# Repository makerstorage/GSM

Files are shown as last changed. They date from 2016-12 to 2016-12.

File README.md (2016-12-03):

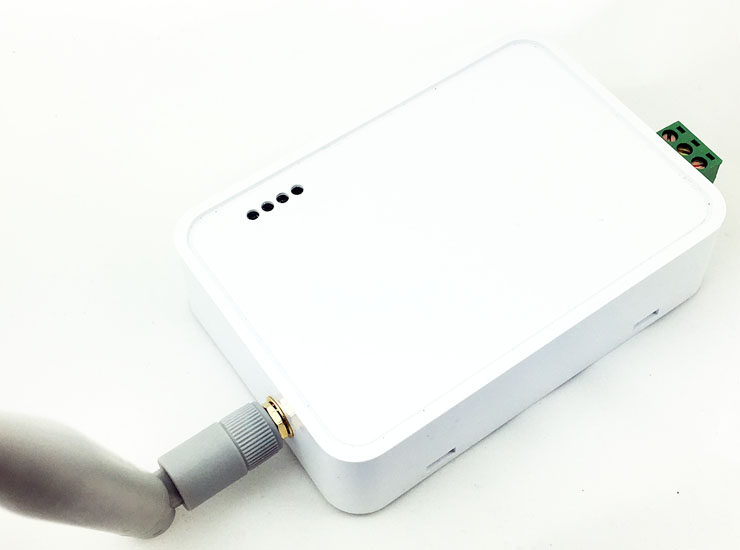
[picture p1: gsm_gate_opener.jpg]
GSM Gate Opener


**GSM Gate Opener**

For more details, check out the blog pages at

http://blog.makerstorage.com

MakerStorage invests time and resources providing this open source design, please support MakerStorage and open-source hardware by purchasing products from MakerStorage!

Designed by MakerStorage LLC.

Creative Commons Attribution, Share-Alike license, check https://creativecommons.org/licenses/by-sa/3.0/ for more information All text above must be included in any redistribution

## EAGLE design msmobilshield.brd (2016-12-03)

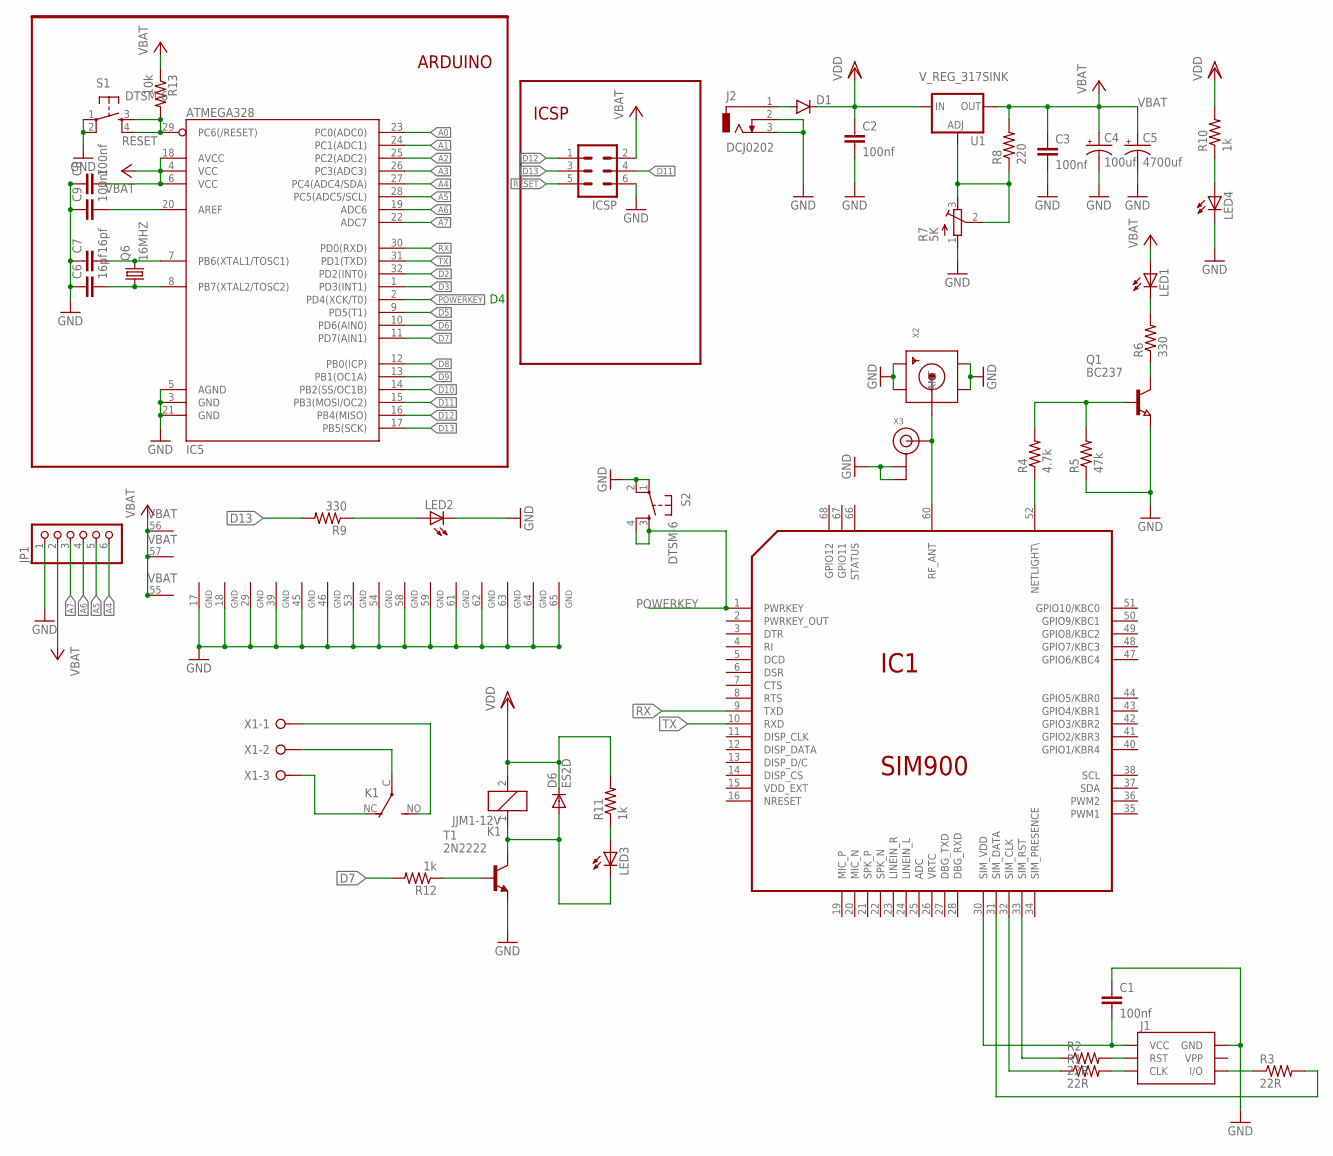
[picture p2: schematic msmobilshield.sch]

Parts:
C1, C2, C3, C8, C9: 100nf; C0805
C4: 100uf; CPOL-RADIAL-100UF-25V
C5: 4700uf; CPOL-RADIAL-1000UF-25V
C6, C7: 16pf; C0805
D1: DIODESMA; SMA-DIODE
D6: ES2D; SMB
IC1: SIM900
IC5: ATMEGA328; TQFP32-08
ICSP: ML6
J1: SIMHOLDERSIM; SIMHOLDER
J2: DCJ0202
JP1: PINHD-1X6; 1X06
K1: JJM1-12V; JJM1C
LED1, LED2, LED3, LED4: LEDCHIPLED_0805; CHIPLED_0805
Q1: BC237; SOT23
Q6: 16MHZ; HC49/S
R1, R2, R3: 22R; R0805
R4: 4.7k; R0805
R5: 47k; R0805
R6, R9: 330; R0805
R7: 5K; RTRIM3103
R8: 220; R0805
R10, R11, R12: 1k; R0805
R13: 10k; R0805
S1, S2: DTSM-6
T1: 2N2222; SOT23-BEC
U1: V_REG_317SINK; TO220-ADJ
X1: W237-3E
X2: SMACONNECTOR; SMA90_DIP
X3: ANTENNA_U.FL; U.FL

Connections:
A0: IC5.23 (PC0(ADC0))
A1: IC5.24 (PC1(ADC1))
A2: IC5.25 (PC2(ADC2))
A3: IC5.26 (PC3(ADC3))
A4: IC5.27 (PC4(ADC4/SDA)), JP1.6
A5: IC5.28 (PC5(ADC5/SCL)), JP1.5
A6: IC5.19 (ADC6), JP1.4
A7: IC5.22 (ADC7), JP1.3
D2: IC5.32 (PD2(INT0))
D3: IC5.1 (PD3(INT1))
D5: IC5.9 (PD5(T1))
D6: IC5.10 (PD6(AIN0))
D7: IC5.11 (PD7(AIN1)), R12.2
D8: IC5.12 (PB0(ICP))
D9: IC5.13 (PB1(OC1A))
D10: IC5.14 (PB2(SS/OC1B))
D11: IC5.15 (PB3(MOSI/OC2)), ICSP.4
D12: IC5.16 (PB4(MISO)), ICSP.1
D13: IC5.17 (PB5(SCK)), ICSP.3, R9.2
GND: C1.1, C2.2, C3.2, C4.2 (-), C5.-, C6.1, C7.1, C8.1, C9.1, IC1.17 (GND), IC1.18 (GND), IC1.29 (GND), IC1.39 (GND), IC1.45 (GND), IC1.46 (GND), IC1.53 (GND), IC1.54 (GND), IC1.58 (GND), IC1.59 (GND), IC1.61 (GND), IC1.62 (GND), IC1.63 (GND), IC1.64 (GND), IC1.65 (GND), IC5.3 (GND), IC5.5 (AGND), IC5.21 (GND), ICSP.6, J1.C5 (GND), J2.2, J2.3, JP1.1, LED2.C, LED4.C, Q1.2 (E), R5.1, R7.1 (A), S1.1, S1.2, S2.1, S2.2, T1.E, X2.GND1, X2.GND2, X2.GND3, X2.GND4, X3.1 (GND), X3.2 (GND)
unnamed: J1.C2 (RST), R2.2
unnamed: J1.C3 (CLK), R1.2
unnamed: J1.C7 (I/O), R3.1
unnamed: IC1.33 (SIM_RST), R2.1
unnamed: IC1.32 (SIM_CLK), R1.1
unnamed: IC1.31 (SIM_DATA), R3.2
unnamed: C1.2, IC1.30 (SIM_VDD), J1.C1 (VCC)
unnamed: IC1.60 (RF_ANT), X2.ANTENNA (ANT), X3.3 (SIGNAL)
unnamed: IC1.52 (NETLIGHT\), R4.1
unnamed: Q1.1 (B), R4.2, R5.2
unnamed: K1.C, X1.2
unnamed: Q1.3 (C), R6.1
unnamed: LED1.C, R6.2
unnamed: K1.NC (O), X1.3
unnamed: D1.A, J2.1
unnamed: K1.NO (S), X1.1
unnamed: R7.2 (S), R7.3 (E), R8.1, U1.ADJ
unnamed: LED2.A, R9.1
unnamed: LED4.A, R10.1
unnamed: C7.2, IC5.7 (PB6(XTAL1/TOSC1)), Q6.2
unnamed: C6.2, IC5.8 (PB7(XTAL2/TOSC2)), Q6.1
unnamed: C9.2, IC5.20 (AREF)
unnamed: R12.1, T1.B
unnamed: D6.A, K1.1, LED3.C, T1.C
unnamed: LED3.A, R11.1
POWERKEY: IC1.1 (PWRKEY), IC5.2 (PD4(XCK/T0)), S2.3, S2.4
RESET: IC5.29 (PC6(/RESET)), ICSP.5, R13.2, S1.3, S1.4
RX: IC1.9 (TXD), IC5.30 (PD0(RXD))
TX: IC1.10 (RXD), IC5.31 (PD1(TXD))
VBAT: C3.1, C4.1 (+), C5.+, C8.2, IC1.55 (VBAT), IC1.56 (VBAT), IC1.57 (VBAT), IC5.4 (VCC), IC5.6 (VCC), IC5.18 (AVCC), ICSP.2, JP1.2, LED1.A, R8.2, R13.1, U1.OUT
VDD: C2.1, D1.C, D6.C, K1.2, R10.2, R11.2, U1.IN

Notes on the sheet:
ICSP
ARDUINO

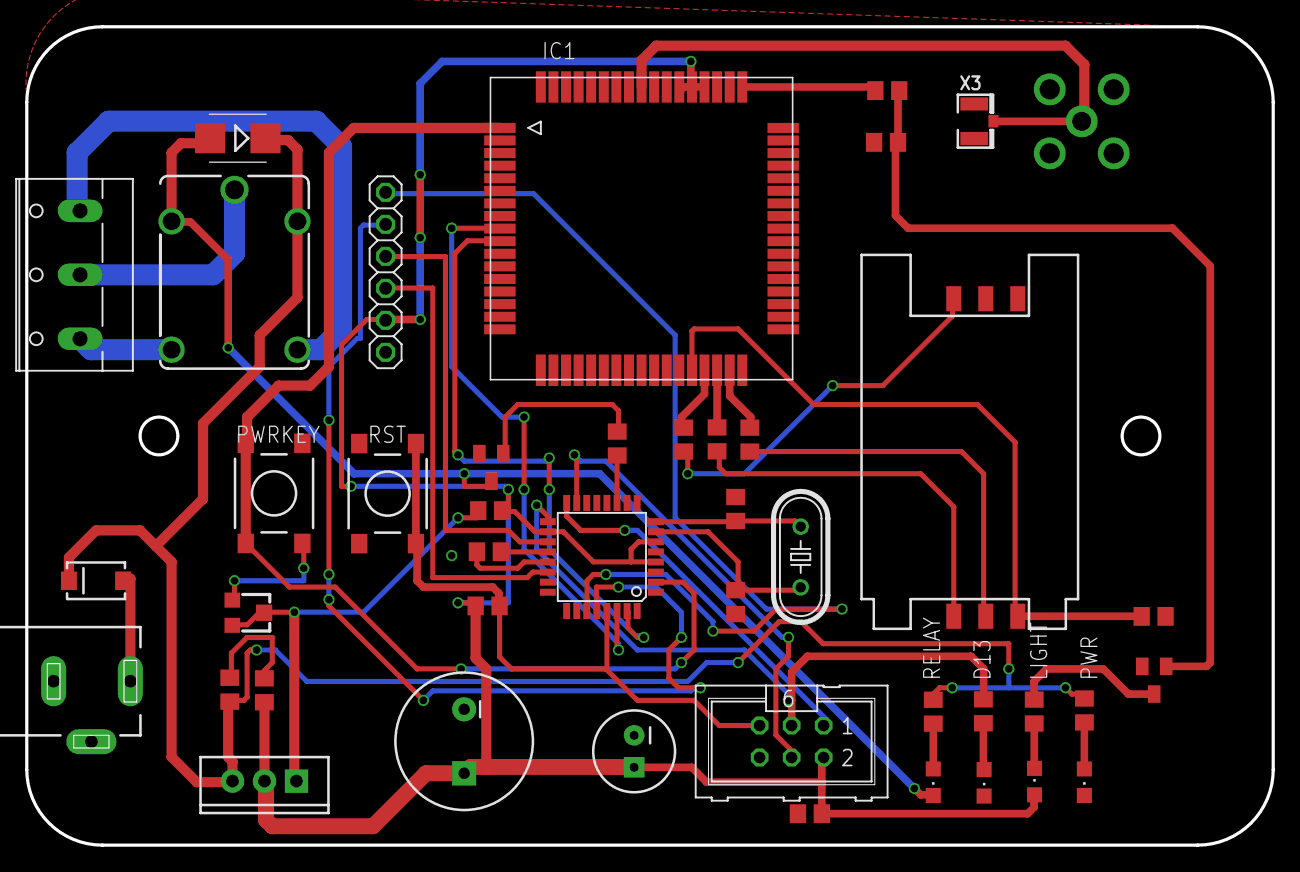
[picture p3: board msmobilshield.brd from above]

Board: 2 copper layers, 99.0 x 65.0 mm, 44 parts (0 on the bottom side), 40 nets.

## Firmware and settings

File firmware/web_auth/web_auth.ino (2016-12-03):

/*  
 *  GPRS/GSM Quadband Module (SIM900)
 *  
 *  Copyright (C) Libelium Comunicaciones Distribuidas S.L. 
 *  http://www.libelium.com 
 *  
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
 *  Version:           2.0
 *  Design:            David Gascón 
 *  Implementation:    Alejandro Gallego & Marcos Martinez
 */
 
int8_t answer;
int onModulePin= 4; //sim9000 powerpin
int relayPin= 7; //relaypin
int debugLed= 13; //relaypin


char aux_str[100];


char apn[]="internet";
char user_name[]="";
char password[]="";
char IP_address[]="192.241.226.168";
char port[]="80";

char ip_data[64];

int inComing = 0;
char gprsBuffer[64];

#define DEFAULT_TIMEOUT          5   //seconds
#define DEFAULT_INTERCHAR_TIMEOUT 1500   //miliseconds
void  sim900_read_buffer(char* buffer,int count,  unsigned int timeout = DEFAULT_TIMEOUT, unsigned int chartimeout = DEFAULT_INTERCHAR_TIMEOUT);


void setup(){

    pinMode(onModulePin, OUTPUT);
    pinMode(relayPin, OUTPUT);
    pinMode(debugLed, OUTPUT);
    
    digitalWrite(relayPin, LOW); // make sure relay is off
    digitalWrite(debugLed, LOW); 
    
    Serial.begin(9600); 

    power_on();
    
    delay(3000);
    digitalWrite(debugLed, HIGH);
    
    while( sendATcommand2("AT+CREG?", "+CREG: 0,1", "+CREG: 0,5", 1000)== 0 );

    //Serial.println("Modul ready");
    
    digitalWrite(debugLed, LOW); //means Modul ready

    uint8_t x=0,  answer=0;
    char response[100];

    sendATcommand("AT+CLIP=1", "OK", 2000);
   
}


String getPhoneNumber(String mygprsBuffer){
String temp;

temp=mygprsBuffer.substring(19,31);
//+CLIP: "+905327945990",145,"",,"",0
//Serial.print(temp);
return temp; 
}

void loop(){

   String incomingPhoneNumber;
  
   if((Serial.available() != 0)) {
       inComing = 1;
   }else{ delay(100);}
   
   if(inComing){
      sim900_read_buffer(gprsBuffer,32,DEFAULT_TIMEOUT);
      //Serial.print(gprsBuffer);
      
      if(NULL != strstr(gprsBuffer,"RING")) {
          
          incomingPhoneNumber = getPhoneNumber(gprsBuffer);
          delay(1000);
          sendATcommand("ATH", "OK", 2000);
          sim900_clean_buffer(gprsBuffer,64);
          
       
          if (auth_web(incomingPhoneNumber)){
            digitalWrite(relayPin, HIGH); //relay open for 2.5 sec
            delay(2500);
            digitalWrite(relayPin, LOW);
            //Serial.println("Yetkili Numara");
          } else {
            //Serial.println("Yetkisiz Numara");
          }
         
          
          sendATcommand2("AT+CIPSHUT", "OK", "ERROR", 10000);
          delay(3000);
      }

      
     sim900_clean_buffer(gprsBuffer,32);  
     inComing = 0;
   }  
 
   

}

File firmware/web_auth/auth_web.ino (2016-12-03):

boolean auth_web(String myPhoneNumber){
String temp ="";
boolean result=false;

temp  = "GET http://m2m.makerstorage.com/index.php?phone="+myPhoneNumber+"\r\n";
temp.toCharArray(ip_data, 64) ;

//Serial.println("tcp message:");
//Serial.println(ip_data);

 // Selects Single-connection mode
    if (sendATcommand2("AT+CIPMUX=0", "OK", "ERROR", 1000) == 1)
    {
        // Waits for status IP INITIAL
        while(sendATcommand("AT+CIPSTATUS", "INITIAL", 500)  == 0 );
       // delay(100);
        
        snprintf(aux_str, sizeof(aux_str), "AT+CSTT=\"%s\",\"%s\",\"%s\"", apn, user_name, password);
         
        // Sets the APN, user name and password
        if (sendATcommand2(aux_str, "OK",  "ERROR", 30000) == 1)
        {            
            // Waits for status IP START
            while(sendATcommand("AT+CIPSTATUS", "START", 500)  == 0 );
            //delay(100);
            
            // Brings Up Wireless Connection
            if (sendATcommand2("AT+CIICR", "OK", "ERROR", 30000) == 1)
            {
                // Waits for status IP GPRSACT
                while(sendATcommand("AT+CIPSTATUS", "GPRSACT", 500)  == 0 );
                //delay(100);
                
                // Gets Local IP Address
                if (sendATcommand2("AT+CIFSR", ".", "ERROR", 10000) == 1)
                {
                    // Waits for status IP STATUS
                    while(sendATcommand("AT+CIPSTATUS", "IP STATUS", 500)  == 0 );
                   // delay(100);
                    //Serial.println("Opening TCP");
                    
                    snprintf(aux_str, sizeof(aux_str), "AT+CIPSTART=\"TCP\",\"%s\",\"%s\"", IP_address, port);
                    
                    // Opens a TCP socket
                    if (sendATcommand2(aux_str, "CONNECT OK", "CONNECT FAIL", 30000) == 1)
                    {
                       // Serial.println("Connected");
                        
                        // Sends some data to the TCP socket
                        sprintf(aux_str,"AT+CIPSEND=%d", strlen(ip_data));
                        if (sendATcommand2(aux_str, ">", "ERROR", 10000) == 1)    
                        {
                            sendATcommand2(ip_data, "SEND OK", "ERROR", 10000);
                          //  delay(100);
                            sim900_read_buffer(gprsBuffer,10,DEFAULT_TIMEOUT);
                            //Serial.println("serverdan cevap:");
                            //Serial.println(gprsBuffer);
                            if(NULL != strstr(gprsBuffer,"true")) {
                              result=true;
                            } else {result=false;}

                            sim900_clean_buffer(gprsBuffer,64);
                        }
                        
                        // Closes the socket
                        sendATcommand2("AT+CIPCLOSE", "CLOSE OK", "ERROR", 10000);
                    }
                    else
                    {
                        //Serial.println("Error opening the connection");
                    }  
                }
                else
                {
                    //Serial.println("Error getting the IP address");
                }  
            }
            else
            {
                //Serial.println("Error bring up wireless connection");
            }
        }
        else
        {
            //Serial.println("Error setting the APN");
        } 
    }
    else
    {
        //Serial.println("Error setting the single connection");
    }

    return result;
    
  
}

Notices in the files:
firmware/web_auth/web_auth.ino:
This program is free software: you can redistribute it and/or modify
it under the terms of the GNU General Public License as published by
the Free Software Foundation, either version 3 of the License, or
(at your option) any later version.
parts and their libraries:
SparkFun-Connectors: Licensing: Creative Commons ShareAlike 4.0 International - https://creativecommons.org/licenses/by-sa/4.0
